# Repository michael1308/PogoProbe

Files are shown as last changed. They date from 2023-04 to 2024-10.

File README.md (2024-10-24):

## PogoProbe

## Description
A TC2030-compatible pogo pin debug/programming probe.

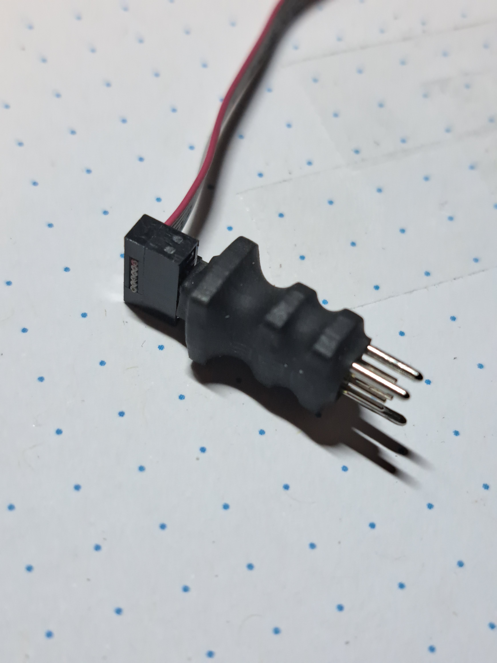
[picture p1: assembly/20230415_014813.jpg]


## Materials:
1. 1x PogoProbe PCB
2. 6x P50-J1 Pogo Pins
3. 3x M0.9 x 20mm steel guiding rod
4. 1x P1.27mm 2x03 SMD Header
5. Super Glue and a PCB with a TC2030 footprint

## Assembly Instructions:

1.  Separate the PCBs from the panel.

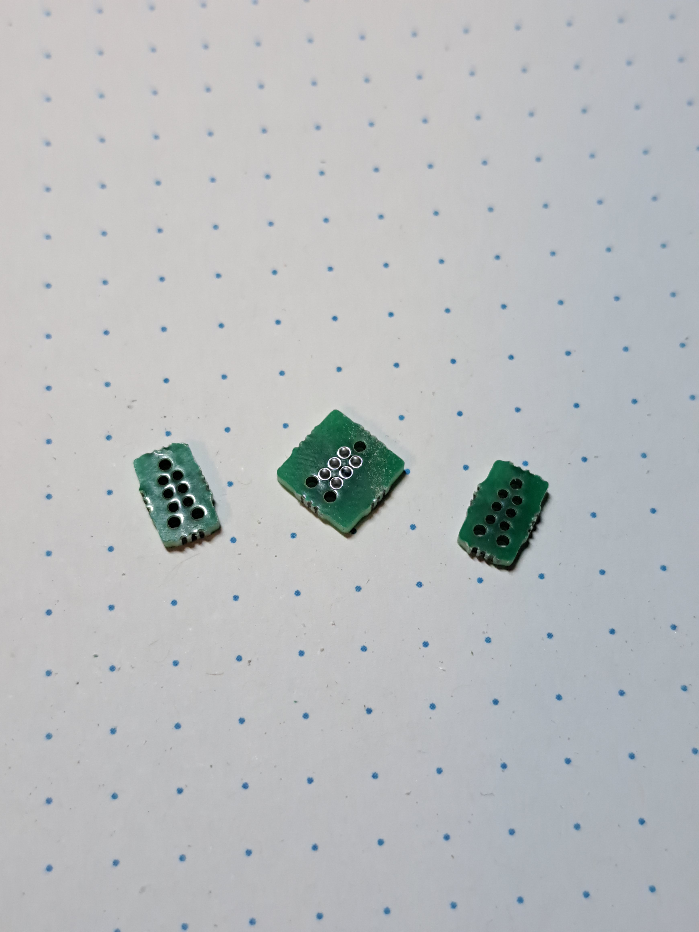
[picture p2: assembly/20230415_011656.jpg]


2.  Add the guiding pins and glue them with a drop of superglue. Be careful not to pour any superglue into the other 6 holes. I used tape to cover the pogo pin holes.

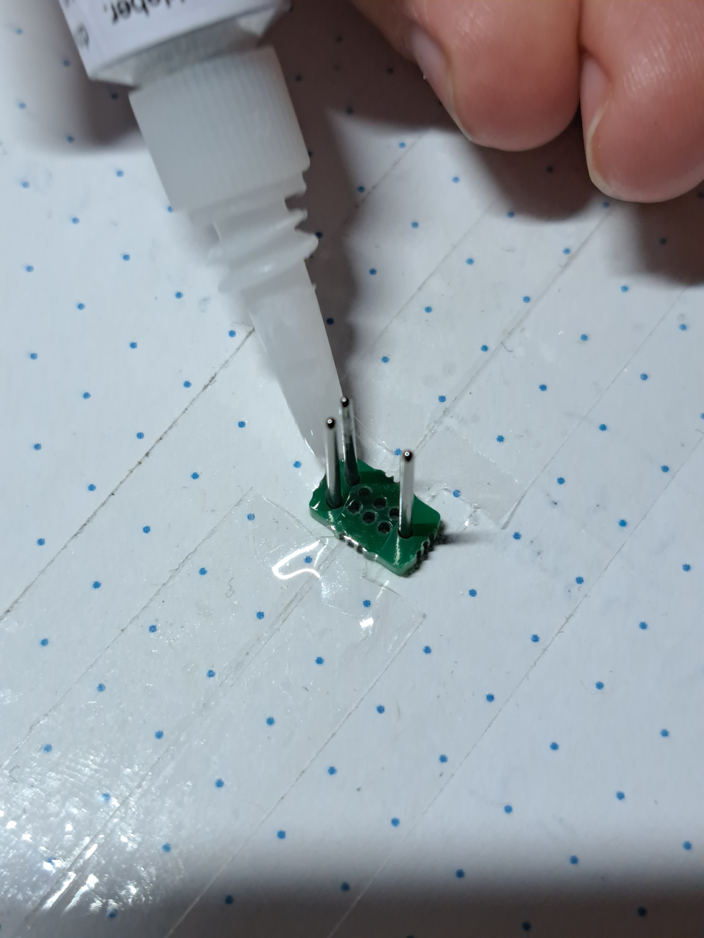
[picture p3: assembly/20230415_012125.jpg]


3.  Using a PCB that has the TC2030 footprint, insert the assembly into the guiding holes. Now insert the 6 pogo pins until they sit on the PCB. Glue them to the PCB with superglue.

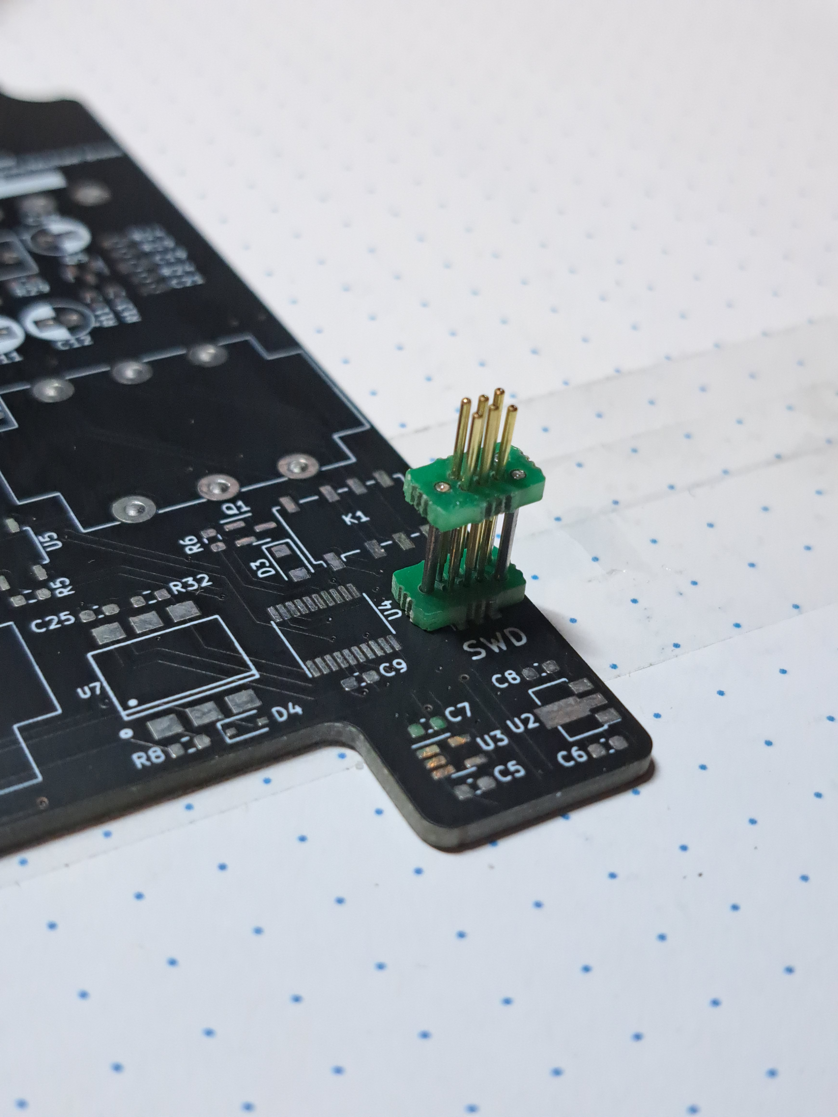
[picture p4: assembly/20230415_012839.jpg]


4.  Glue the second PCB on the front side of the probe. I tried going for a 5mm offset from the end of the guiding pins.

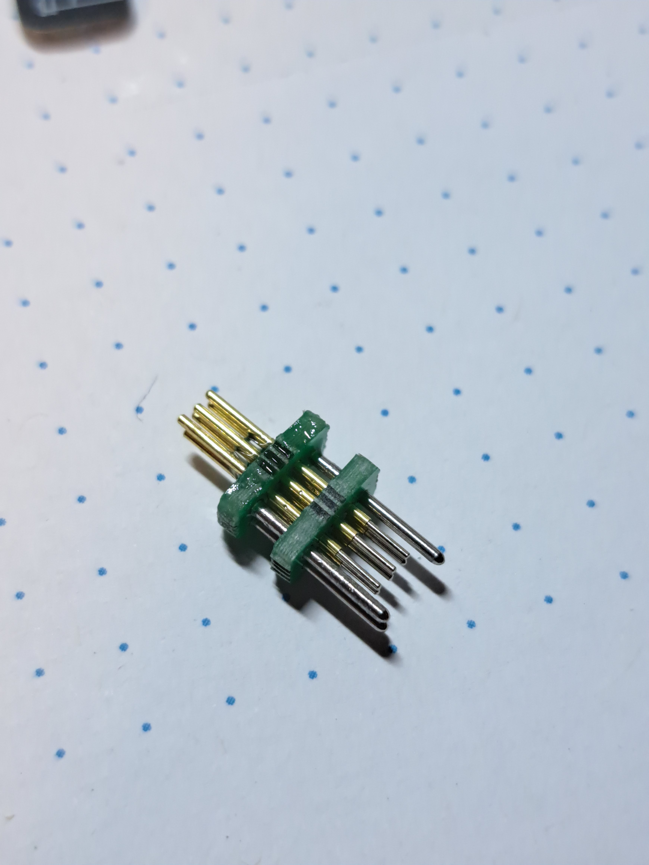
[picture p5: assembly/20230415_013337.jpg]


5.  Add the bottom PCB and fix it in place by soldering one of the pins. Now carefully solder the remaining pins, being careful to have them flush to the surface of the PCB.

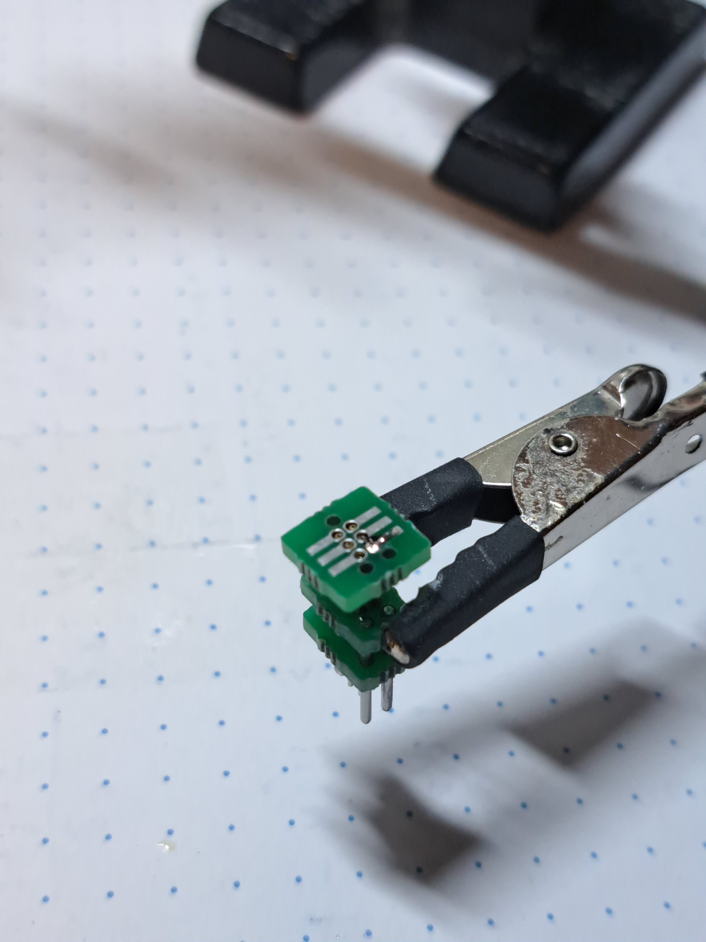
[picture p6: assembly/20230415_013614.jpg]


6.  Solder the 2x03 IDC Header over the ends of the pins. This step can be a bit tricky but try going slow to avoid solder bridges.

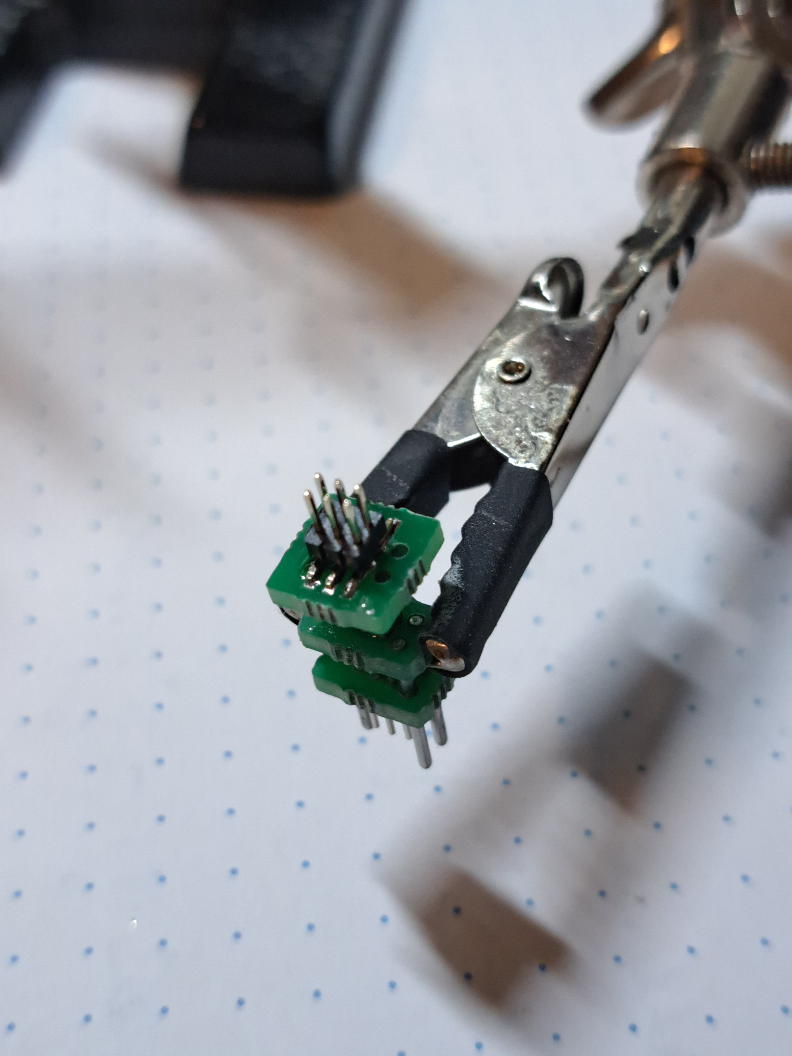
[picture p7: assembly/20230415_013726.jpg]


7. At this point the probe should be functional. Test the contacts with a multimeter and also test that the pogopins are still moving. You can leave it like this, put some heatshrink over it, or even better, encase the middle part in epoxy. For my probe I went with heatshrink since it is faster.



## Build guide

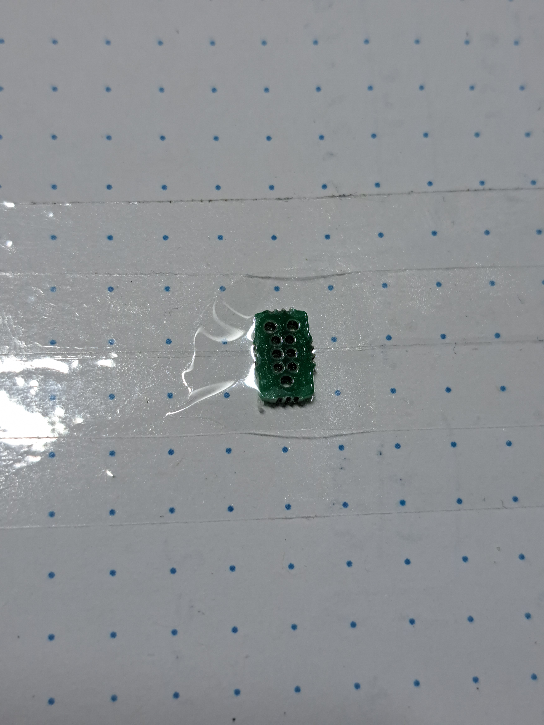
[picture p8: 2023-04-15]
assembly/20230415_012003.jpg

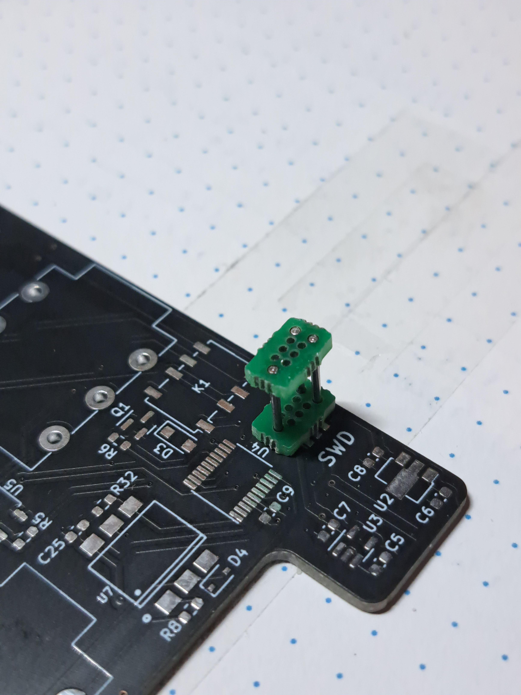
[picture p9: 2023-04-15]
assembly/20230415_012658.jpg

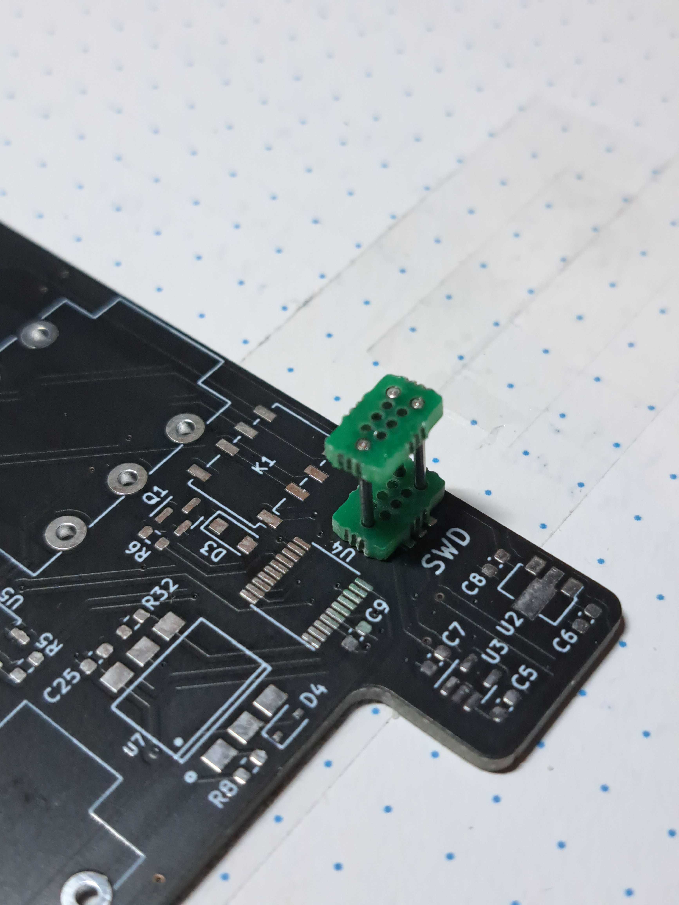
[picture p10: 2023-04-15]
assembly/20230415_012654.jpg

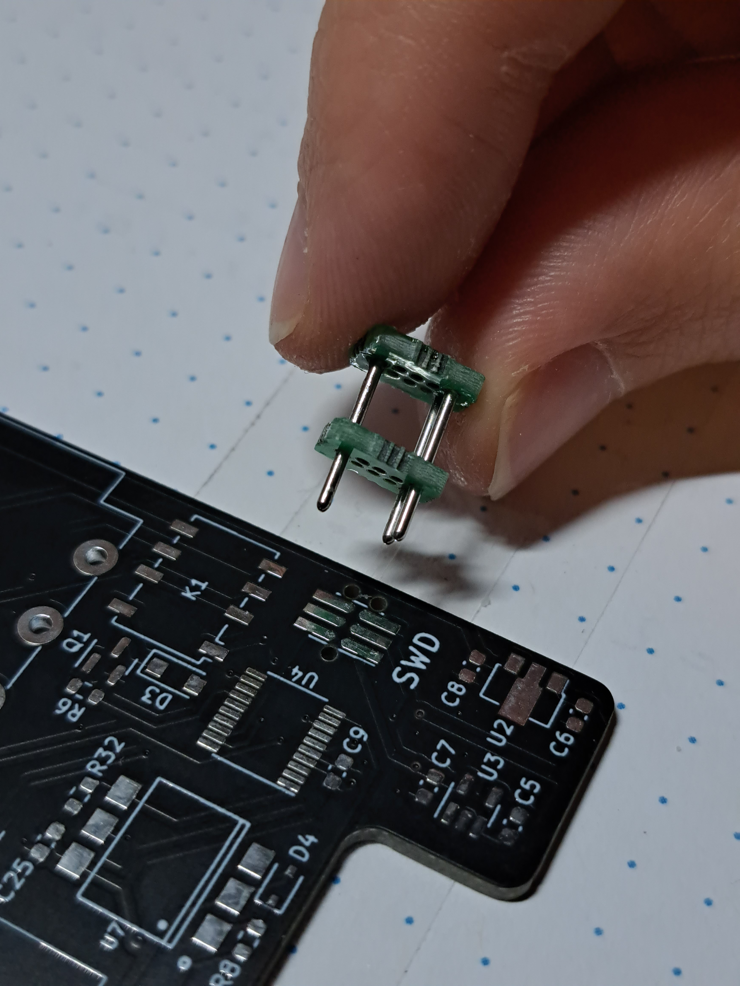
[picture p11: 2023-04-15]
assembly/20230415_012639.jpg

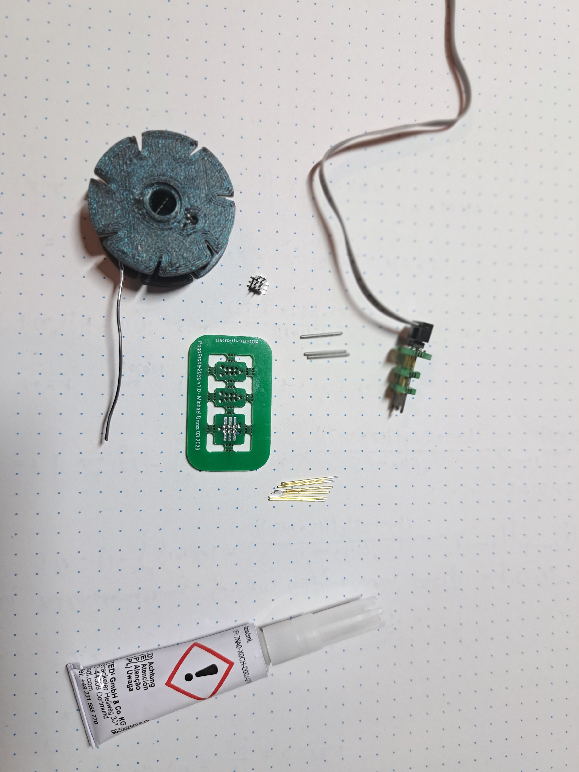
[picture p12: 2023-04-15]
assembly/20230415_011019.jpg

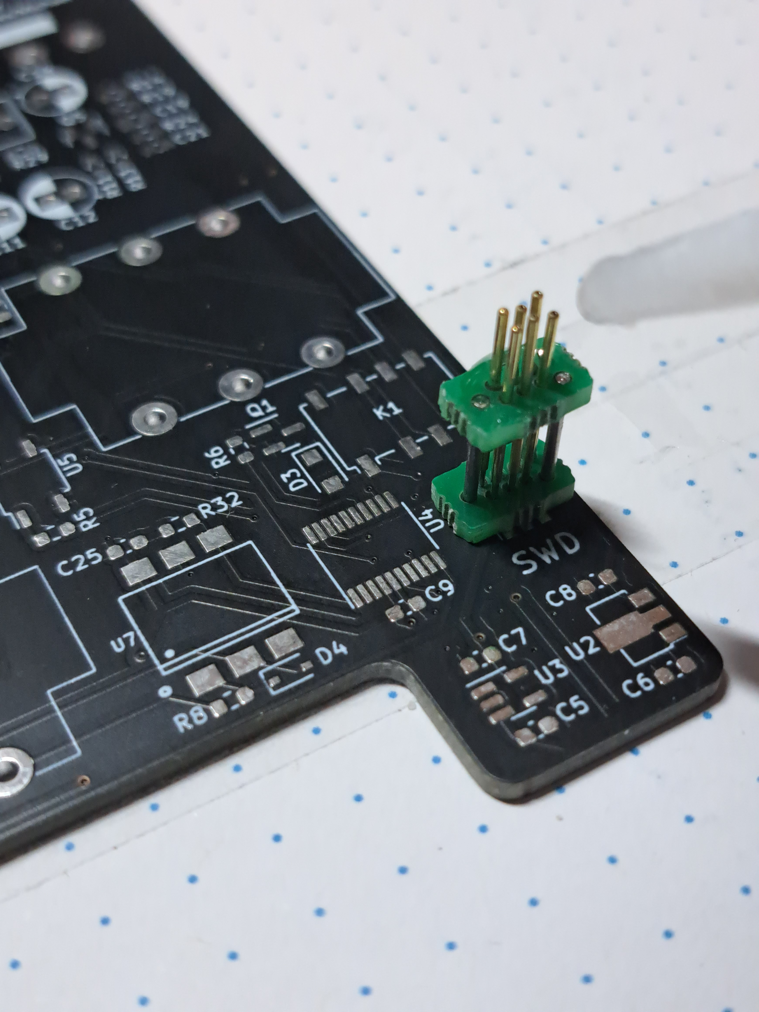
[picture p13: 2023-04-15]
assembly/20230415_012856.jpg

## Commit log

2023-04-15 added assembly instructions
2023-04-15 dded assembly instructions
2024-10-24 Drop files from .gitignore
    [PogoProbe 2030.kicad_pcb, PogoProbe 2030.kicad_sch]
2024-10-24 rename folders
    [PogoProbe 2030-B_Cu.gbr, PogoProbe 2030-B_Mask.gbr, PogoProbe 2030-B_Paste.gbr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]
